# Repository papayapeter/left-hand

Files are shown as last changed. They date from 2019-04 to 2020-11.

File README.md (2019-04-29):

# left-hand
a robotic hand that reacts to touch by gripping the touching hand

documentation: [https://zenogries.com/portfolio/wasmachstduda/](https://zenogries.com/portfolio/wasmachstduda/)

## libraries
* [Metro](https://github.com/thomasfredericks/Metro-Arduino-Wiring) by thomasfredericks
* [AccelStepper](http://www.airspayce.com/mikem/arduino/AccelStepper/) by Mike McCauley

## hardware
* [teensy lc ](https://www.pjrc.com/teensy/teensyLC.html)
* [a4988 stepper driver](https://www.pololu.com/product/1182)
* [nema 17 stepper](https://www.ebay.de/itm/Nema-17-Stepper-Motor-Schrittmotor-26Ncm-12V-0-4A-4-wire-1m-cable-3D-Printer/392163408983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)
* carrier pcb and aluminium skeleton designed by me
* silikon glove

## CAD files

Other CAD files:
inventor/01_hand-plate.ipt
inventor/02_hand-plate.ipt
inventor/index-finger/01_index-finger.ipt
inventor/index-finger/02_index-finger.ipt
inventor/index-finger/03_index-finger.ipt
inventor/index-finger/04_index-finger.ipt
inventor/little-finger/01_little-finger.ipt
inventor/little-finger/02_little-finger.ipt
inventor/little-finger/03_little-finger.ipt
inventor/little-finger/04_little-finger.ipt
inventor/middle-finger/01_middle-finger.ipt
inventor/middle-finger/02_middle-finger.ipt
inventor/middle-finger/03_middle-finger.ipt
inventor/middle-finger/04_middle-finger.ipt
inventor/ring-finger/01_ring-finger.ipt
inventor/ring-finger/02_ring-finger.ipt
inventor/ring-finger/03_ring-finger.ipt
inventor/ring-finger/04_ring-finger.ipt
inventor/thumb/01_tumb.ipt
inventor/thumb/02_tumb.ipt
inventor/thumb/03_tumb.ipt

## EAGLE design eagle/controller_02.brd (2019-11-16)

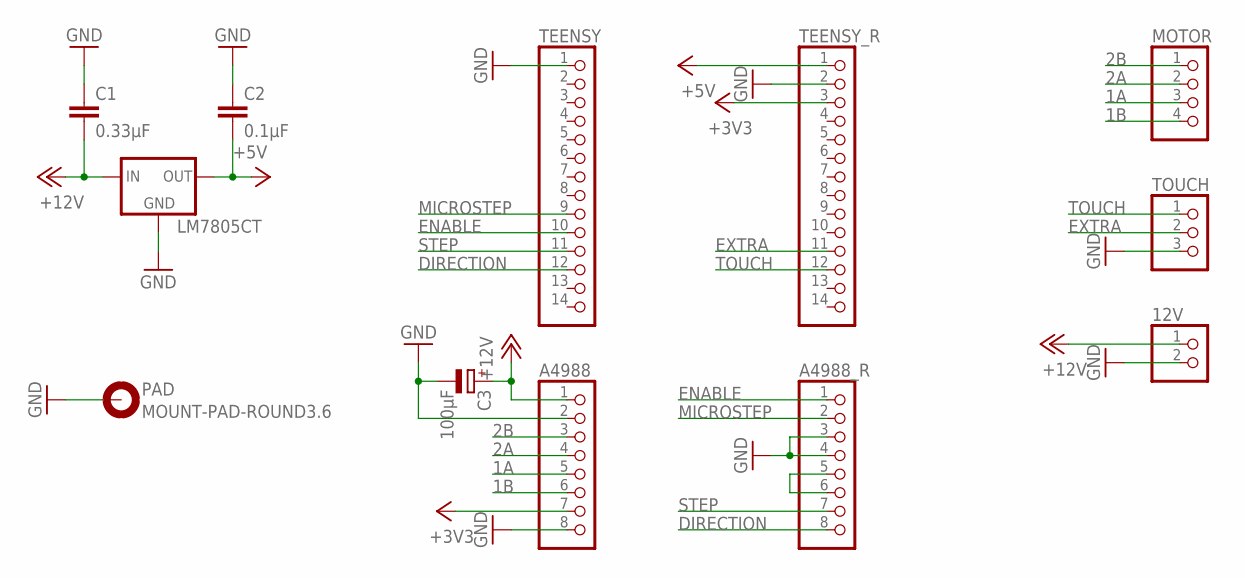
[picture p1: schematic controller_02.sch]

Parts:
12V: PINHD-1X2; 1X02
A4988, A4988_R: PINHD-1X8; 1X08
C1: 0.33µF; C025-025X050
C2: 0.1µF; C025-025X050
C3: 100µF; E3,5-8
LM7805CT: 78XXL
MOTOR: PINHD-1X4; 1X04
PAD: MOUNT-PAD-ROUND3.6; 3,6-PAD
TEENSY: PINHD-1X14; 1X14
TEENSY_R: PINHD-1X14; 1X14
TOUCH: PINHD-1X3; 1X03

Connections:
1A: A4988.5, MOTOR.3
1B: A4988.6, MOTOR.4
2A: A4988.4, MOTOR.2
2B: A4988.3, MOTOR.1
+3V3: A4988.7, TEENSY_R.3
+5V: C2.2, LM7805CT.OUT, TEENSY_R.1
+12V: 12V.1, A4988.1, C1.2, C3.+, LM7805CT.IN
DIRECTION: A4988_R.8, TEENSY.12
ENABLE: A4988_R.1, TEENSY.10
EXTRA: TEENSY_R.11, TOUCH.2
GND: 12V.2, A4988.2, A4988.8, A4988_R.3, A4988_R.4, C1.1, C2.1, C3.-, LM7805CT.GND, PAD.B3,6, TEENSY.1, TEENSY_R.2, TOUCH.3
MICROSTEP: A4988_R.2, TEENSY.9
unnamed: A4988_R.5, A4988_R.6
STEP: A4988_R.7, TEENSY.11
TOUCH: TEENSY_R.12, TOUCH.1

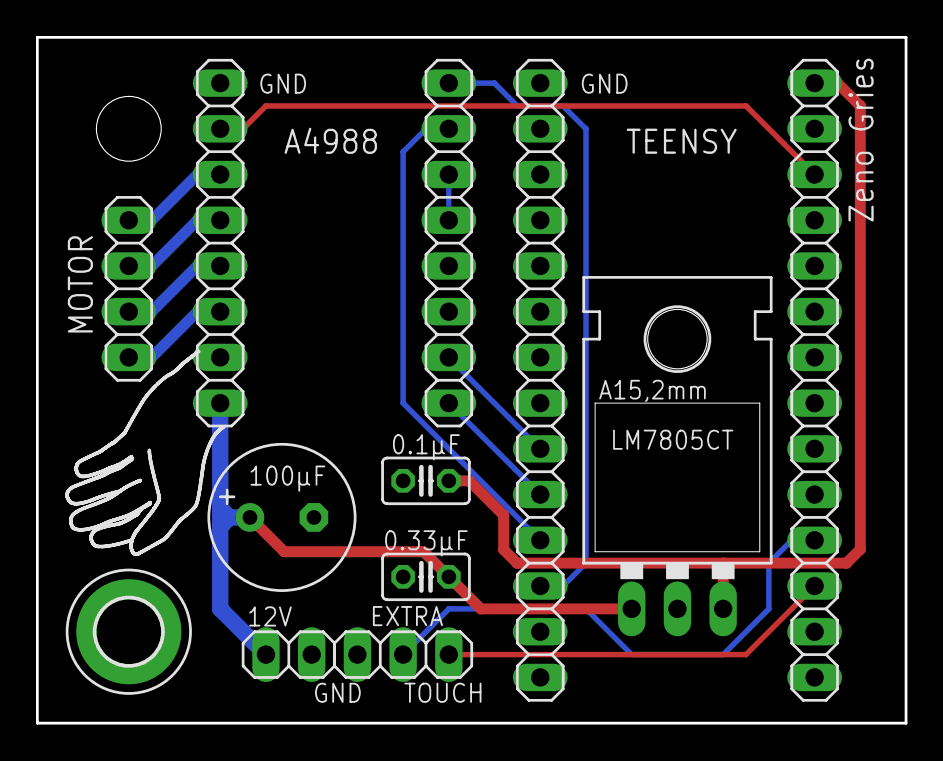
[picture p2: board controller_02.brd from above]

Board: 2 copper layers, 48.3 x 38.1 mm, 12 parts (0 on the bottom side), 15 nets.

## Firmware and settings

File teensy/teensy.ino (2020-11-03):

// *** Zeno Gries - 2018
// *** Die Hände R2.0

#include "hand.h"

// pins ------------------------------------------------------------------------
const uint8_t MICROSTEP = 7;
const uint8_t ENABLE = 8;
const uint8_t STEP = 9;
const uint8_t DIRECTION = 10;
const uint8_t SEED = 14;
const uint8_t TOUCH = 15;
const uint8_t SWITCH = 16;
const uint8_t LED = 13;

// constants -------------------------------------------------------------------
// motor
const uint16_t motorFailsafe = 300;                 // when to stop moving during calibration
const uint16_t motorLimit = 185;                    // what should be the calibrated position
const uint16_t motorMax = 180;                      // what should be the maximum position (always less than the calibrated position)
const uint16_t motorAcceleration = 50;              // how fast does the motor accelerate during closing?
const uint16_t motorMaxSpeed = 50;                  // how fast will the motor go during closing?
const uint16_t motorAccelerationBack = 25;          // how fast does the motor accelerate during opening?
const uint16_t motorMaxSpeedBack = 25;              // how fast will the motor go during opening?
const uint16_t motorAccelerationCalibration = 2000; // how fast does the motor accelerate during calibration?
const uint16_t motorMaxSpeedCalibration = 20;       // how fast will the motor go during calibration?
const uint16_t motorRemainOverstep = 10;             // how many steps will the motor do after the audience let go?
const uint16_t motorRemainTime = 1000;               // how long does the hand remain still aufter being let go?
const uint16_t motorRemainThreshhold = 80;          // from which position on does the motor "remain"?

const uint16_t motorMaxCome = 50;                   // full closed position if the "come here" gesture
const uint16_t motorComeTime = 8000;                // duration of the "come here" gesture (full period)

const uint16_t motorWiggleTime = 200;               // wiggle interval (when hand is closed)
const uint16_t motorWiggleMagnitude = 4;            // wiggle magnitude (when hand is closed)

// touch
const uint16_t touchThreshhold = 700;               // how sensitive is the hand towards touch?
const uint16_t calibrationLength = 80;              // how many intervals to read for calibration?
const uint16_t pauseLength = 500;                   // how many intervals between touch and calibration?
const uint16_t touchLength = 20;                    // how many intervals to read for touch?

const uint32_t touchOpen = 60000;                   // when to open the hand after it's last been closed

// objects ---------------------------------------------------------------------
Hand hand(MICROSTEP, ENABLE, STEP, DIRECTION, TOUCH, SWITCH, LED);

// variables -------------------------------------------------------------------
HandState state = OPENING;

uint32_t timeToCalibration;

uint32_t closeTime;

// setup -----------------------------------------------------------------------
void setup()
{
  // set random seed from floating pin
  randomSeed(analogRead(SEED));

  // set motor parameters
  hand.setMotor(motorFailsafe,
                motorLimit,
                motorMax,
                motorAcceleration,
                motorMaxSpeed,
                motorAccelerationBack,
                motorMaxSpeedBack,
                motorAccelerationCalibration,
                motorMaxSpeedCalibration,
                motorRemainOverstep,
                motorRemainTime,
                motorRemainThreshhold,
                motorMaxCome,
                motorComeTime,
                motorWiggleTime,
                motorWiggleMagnitude);

  // set touch parameters
  hand.setTouch(touchThreshhold,
                calibrationLength,
                pauseLength,
                touchLength);

  // set debug parameters and set states
  hand.initialize(true, true, 100);

  // calibrate mechanically
  hand.calibrate();

  // calibrate electrically
  hand.fill(5000);

  // set the first time when to calibrate again after nobody touched the hand
  timeToCalibration = 120000 + random(60000);
}

// loop ------------------------------------------------------------------------
void loop()
{
  // sense for touch and set the proper states
  if (hand.feel())
  {
    if (state == OPENING)
    {
      hand.close();

      // remember when the hand was last closed
      closeTime = millis();
    }
  }
  else
  {
    if (state == CLOSING)
      hand.open();
  }

  // if the hand was last closed before the touchOpen time, then make it open
  if (millis() > closeTime + touchOpen)
  {
    hand.setReading(false);
  }

  // if the time to calibrate after the last touch has elapsed, then calibrate
  if (millis() > hand.getLastTouched() + timeToCalibration)
  {
    timeToCalibration = 120000 + random(60000);

    hand.calibrate();

    hand.fill(3000);
  }

  // run the hand
  state = hand.run();
}

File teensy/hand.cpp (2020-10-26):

#include "hand.h"

// methods ---------------------------------------------------------------------

// setMotor --------------------------------------------------------------------
void Hand::setMotor(uint16_t failsafe,
                    uint16_t limit,
                    uint16_t max,
                    uint16_t acceleration,
                    uint16_t speed,
                    uint16_t accelerationBack,
                    uint16_t speedBack,
                    uint16_t accelerationCalibration,
                    uint16_t speedCalibration,
                    uint16_t remainOverstep,
                    uint16_t remainTime,
                    uint16_t remainThreshhold,
                    uint16_t maxCome,
                    uint16_t comeTime,
                    uint16_t wiggleTime,
                    uint16_t wiggleMagnitude)
{
  // copy variables
  motorFailsafe = failsafe;
  motorLimit = limit;
  motorMax = max;
  motorAcceleration = acceleration;
  motorMaxSpeed = speed;
  motorAccelerationBack = accelerationBack;
  motorMaxSpeedBack = speedBack;
  motorAccelerationCalibration = accelerationCalibration;
  motorMaxSpeedCalibration = speedCalibration;
  motorRemainOverstep = remainOverstep;
  motorRemainTime = remainTime;
  motorRemainThreshhold = remainThreshhold;
  motorMaxCome = maxCome;
  motorComeTime = comeTime;
  motorWiggleTime = wiggleTime;
  motorWiggleMagnitude = wiggleMagnitude;
}

// setTouch --------------------------------------------------------------------
void Hand::setTouch(uint16_t threshhold,
                    uint16_t lengthC,
                    uint16_t lengthP,
                    uint16_t lengthT,
                    uint8_t intervalTime)
{
  // copy variables
  touchThreshhold = threshhold;
  touchLength = lengthT;

  calibrationLength = lengthC;
  pauseLength = lengthP;

  // initialize touchStack with proper length
  touchStack = new uint16_t[lengthC + lengthP + lengthT];

  // setup metro timer for read intervals
  timerRead.interval(intervalTime);
  timerRead.reset();
}

// initialize ------------------------------------------------------------------
void Hand::initialize(boolean debug,
                      boolean plot,
                      uint16_t debugTime)
{
  // set state and direction to starting values
  direction = UNSET;
  handState = OPENING;

  // setup debug
  timerDebug.interval(debugTime);
  timerDebug.reset();

  debugging = debug;
  plotting = plot;

  // debug
  if (debugging)
    Serial.begin(9600);

  // set up pins
  pinMode(pinSwitch, INPUT_PULLUP);
  pinMode(pinLed, OUTPUT);
}

// fill ------------------------------------------------------------------------
void Hand::fill(uint32_t duration)
{
  if (debugging && !plotting)
    Serial.println("filling touchStack for " + String(duration) + " ms");

  // turn on led
  digitalWrite(pinLed, HIGH);

  // run the motor back to 0
  motor.moveTo(0);

  // fill the touchstack for the set duration
  uint32_t time = millis();
  while (millis() < time + duration)
  {
    if (timerRead.check())
    {
      // read the touch
      uint16_t value = touchRead(pinTouch);
      // shift every read down
      for (uint16_t i = 0; i < calibrationLength + pauseLength + touchLength - 1; i++)
        touchStack[i] = touchStack[i + 1];
      // put new read on top
      touchStack[calibrationLength + pauseLength + touchLength - 1] = value;
    }

    // run motor
    motor.run();
  }

  // turn off led
  digitalWrite(pinLed, LOW);

  // debug
  if (debugging && !plotting)
    Serial.println("touchStack filled");
}

// calibrate -------------------------------------------------------------------
void Hand::calibrate()
{
  // debug
  if (debugging && !plotting)
    Serial.println("calibrating");

  // turn on led
  digitalWrite(pinLed, HIGH);

  // set new speeds to be used during calibration
  motor.setAcceleration(motorAccelerationCalibration);
  motor.setMaxSpeed(motorMaxSpeedCalibration);

  // move the motor as long as its safe or it hits the switch
  motor.moveTo(motorFailsafe);
  while (digitalRead(pinSwitch))
  {
    motor.run();

    // give error if last safe position is reached but the switch has not been hit
    if (motor.currentPosition() >= motorFailsafe)
    {
      if (debugging) // debug
        Serial.println("error while calibrating");

      while (true)
      {
        digitalWrite(pinLed, HIGH);
        delay(500);
        digitalWrite(pinLed, LOW);
        delay(500);
      }
    }
  }

  // debug
  if (debugging && !plotting)
    Serial.println("calibration result: " + String(motor.currentPosition()) + " -> " + String(motorLimit));

  // if the switch has been hit, set this position as the new limit
  motor.setCurrentPosition(motorLimit);

  // turn off led
  digitalWrite(pinLed, LOW);

  // set lastTouched to now
  lastTouched = millis();

  // debug
  if (debugging && !plotting)
    Serial.println("calibration done");
}

// setReading ------------------------------------------------------------------
void Hand::setReading(boolean readState)
{
  reading = readState;
}
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
